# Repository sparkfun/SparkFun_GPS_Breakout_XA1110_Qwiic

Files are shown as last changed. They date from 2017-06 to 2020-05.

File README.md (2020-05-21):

SparkFun GPS Breakout - XA1110
========================================

SparkFun GPS Breakout - XA1110 (Qwiic) (https://www.sparkfun.com/products/14414)

[*SparkFun GPS Breakout - XA1110 (Qwiic) (SEN-14414)*](https://www.sparkfun.com/products/14414)

The Qwiic GPS uses the Titan X1 GPS module with special I2C firmware. This library talks to the GPS module over I2C.

Repository Contents
-------------------

* **/Hardware** - Eagle design files (.brd, .sch)
* **/Libraries** - Libraries for use with the SparkFun GPS Breakout
* **/Production** - Production panel files (.brd)

Documentation
--------------
* **[SparkFun I2C GPS Library](https://github.com/sparkfun/SparkFun_I2C_GPS_Arduino_Library)** - C library for the XA1110.
* **[TinyGPS library by MikalHart](https://github.com/mikalhart/TinyGPS)** - C library for the XA1110.
* **[Hookup Guide](https://learn.sparkfun.com/tutorials/sparkfun-gps-breakout---xa1110-qwiic-hookup-guide)** - Basic hookup guide for the XA1110 GPS.
* **[SparkFun Fritzing repo](https://github.com/sparkfun/Fritzing_Parts)** - Fritzing diagrams for SparkFun products.
* **[SparkFun 3D Model repo](https://github.com/sparkfun/3D_Models)** - 3D models of SparkFun products. 
* **[SparkFun Graphical Datasheets](https://github.com/sparkfun/Graphical_Datasheets)** -Graphical Datasheets for various SparkFun products.

Product Versions
----------------
* [SEN-14414](https://www.sparkfun.com/products/14414)- The Qwiic GPS uses the Titan X1 GPS module with special I2C firmware. This library talks to the GPS module over I2C.

Version History
---------------
* [v1.0.0](https://github.com/sparkfun/SparkFun_GPS_Breakout_XA1110_Qwiic/releases/tag/V_1.0.0) - Initial Release

License Information
-------------------

This product is _**open source**_! 

Please review the LICENSE.md file for license information. 

If you have any questions or concerns on licensing, please contact techsupport@sparkfun.com.

Distributed as-is; no warranty is given.

- Your friends at SparkFun.

_<COLLABORATION CREDIT>_

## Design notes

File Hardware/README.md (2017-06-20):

SparkFun <PRODUCT NAME> Design Files
=====================================

The .sch and .brd files hare are Eagle CAD schematic and PCB design files from SparkFun Electronics.
A freeware version of Eagle can be found [here](http://www.cadsoftusa.com/download-eagle/freeware/).

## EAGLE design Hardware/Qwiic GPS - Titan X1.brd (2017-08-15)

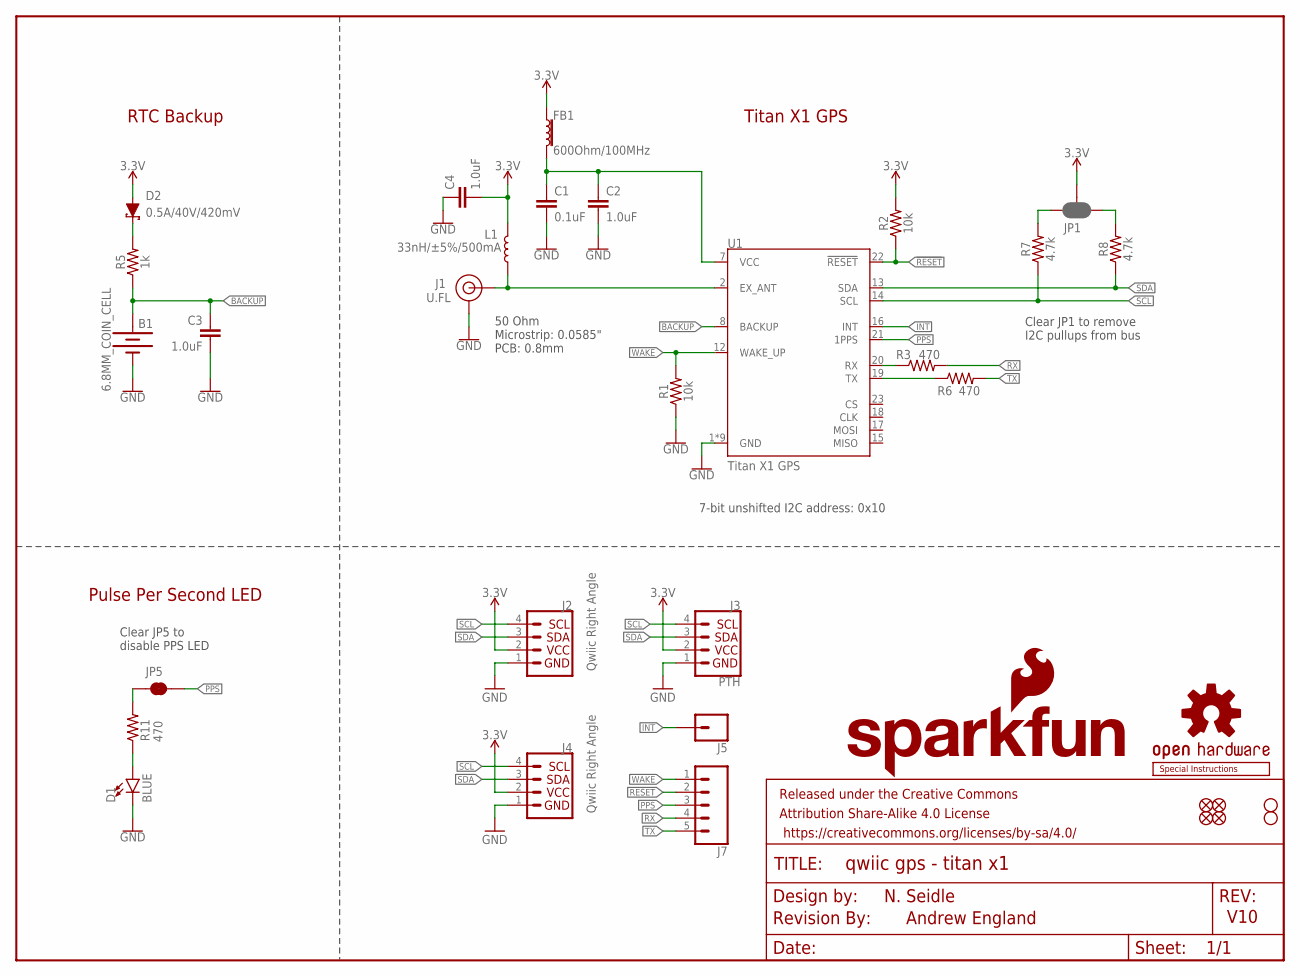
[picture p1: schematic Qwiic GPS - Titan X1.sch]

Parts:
B1: 6.8MM_COIN_CELL; BATTCON-6.8MM
C1: 0.1uF; 0603
C2, C3, C4: 1.0uF; 0603
D1: BLUE; LED-0603
D2: 0.5A/40V/420mV; SOD-323
FB1: 600Ohm/100MHz; 0603
FRAME1: FRAME-LETTER; CREATIVE_COMMONS
J1: U.FL
J2, J4: Qwiic Right Angle; 1X04_1MM_RA
J3: PTH; 1X04_NO_SILK
J5: CONN_01PTH_NO_SILK_YES_STOP; 1X01_NO_SILK
J7: CONN_05NO_SILK; 1X05_NO_SILK
JP1: JUMPER-SMT_3_2-NC_PASTE_SILK; SMT-JUMPER_3_2-NC_PASTE_SILK
JP2, JP6, JP7, JP8: FIDUCIALUFIDUCIAL; MICRO-FIDUCIAL
JP3, JP4: STAND-OFF
JP5: JUMPER-SMT_2_NC_TRACE_NO-SILK; SMT-JUMPER_2_NC_TRACE_NO-SILK
L1: 33nH/±5%/500mA; 0603
LOGO1: OSHW-LOGOMINI; OSHW-LOGO-MINI
LOGO2: SFE_LOGO_NAME_FLAME.1_INCH; SFE_LOGO_NAME_FLAME_.1
LOGO3: REVISION
R1, R2: 10k; 0603
R3, R6, R11: 470; 0603
R5: 1k; 0603
R7, R8: 4.7k; 0603
U1: Titan X1 GPS; TITAN_X1_GPS
U$3: SPECIAL_INSTRUCTIONS-PRODUCTION; PRODUCTION_INSTRUCTIONS

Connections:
3.3V: C4.2, D2.A, FB1.1, J2.2, J3.2 (VCC), J4.2, JP1.2, L1.2, R2.2
!RESET: J7.2, R2.1, U1.22 (!RESET)
BACKUP: B1.+, C3.1, R5.1, U1.8 (BACKUP)
EXT_ANT: J1.FEED (SIGNAL), L1.1, U1.2 (EX_ANT)
GND: B1.-, C1.2, C2.2, C3.2, C4.1, D1.C, J1.1 (GND), J1.2 (GND), J2.1, J3.1 (GND), J4.1, R1.1, U1.1 (GND), U1.3 (GND), U1.4 (GND), U1.5 (GND), U1.6 (GND), U1.9 (GND), U1.10 (GND), U1.11 (GND), U1.24 (GND)
INT: J5.1, U1.16 (INT)
unnamed: D1.A, R11.1
unnamed: JP5.1, R11.2
unnamed: JP1.1, R8.2
unnamed: D2.C, R5.2
unnamed: JP1.3, R7.2
PPS: J7.3, JP5.2, U1.21 (1PPS)
RX: J7.4, R3.2
RXLV: R3.1, U1.20 (RX)
SCL: J2.4, J3.4 (SCL), J4.4, R7.1, U1.14 (SCL)
SDA: J2.3, J3.3 (SDA), J4.3, R8.1, U1.13 (SDA)
TX: J7.5, R6.2
TXLV: R6.1, U1.19 (TX)
VCC_FILTERED: C1.1, C2.1, FB1.2, U1.7 (VCC)
WAKE: J7.1, R1.2, U1.12 (WAKE_UP)

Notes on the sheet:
N. Seidle
V10
7-bit unshifted I2C address: 0x10
Titan X1 GPS
RTC Backup
Pulse Per Second LED
50 Ohm Microstrip: 0.0585" PCB: 0.8mm
Andrew England
Clear JP1 to remove I2C pullups from bus
Clear JP5 to disable PPS LED

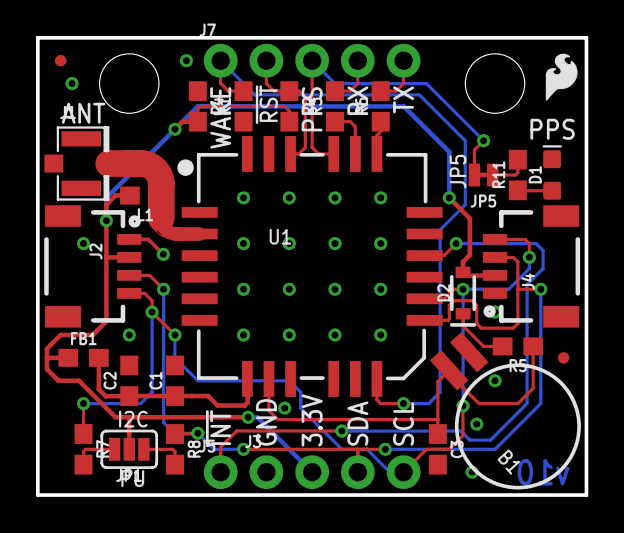
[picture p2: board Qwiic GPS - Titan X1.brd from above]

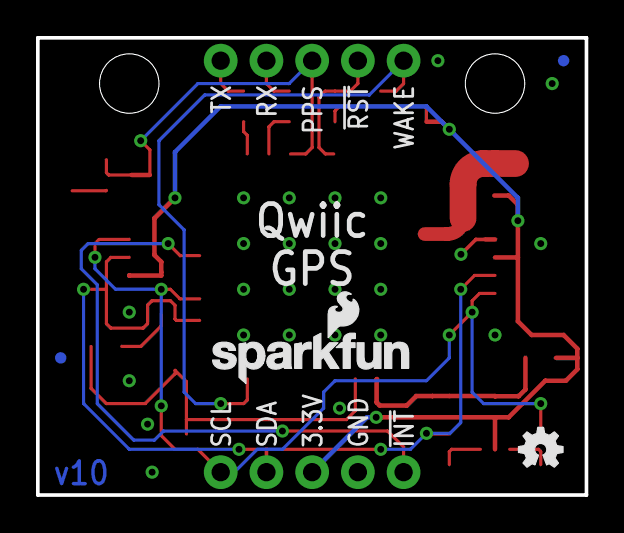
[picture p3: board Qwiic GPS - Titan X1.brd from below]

Board: 2 copper layers, 30.5 x 25.4 mm, 38 parts (4 on the bottom side), 20 nets.

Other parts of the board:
U$2: SFE_LOGO_FLAME_.1

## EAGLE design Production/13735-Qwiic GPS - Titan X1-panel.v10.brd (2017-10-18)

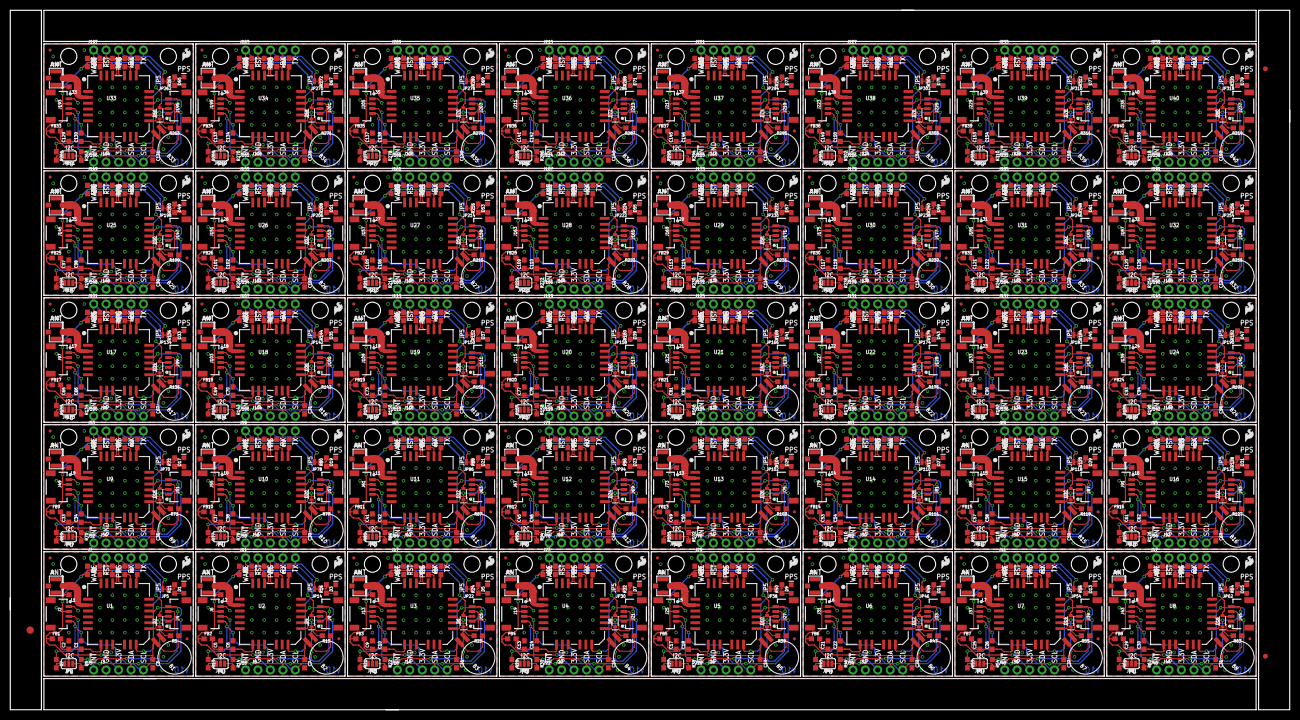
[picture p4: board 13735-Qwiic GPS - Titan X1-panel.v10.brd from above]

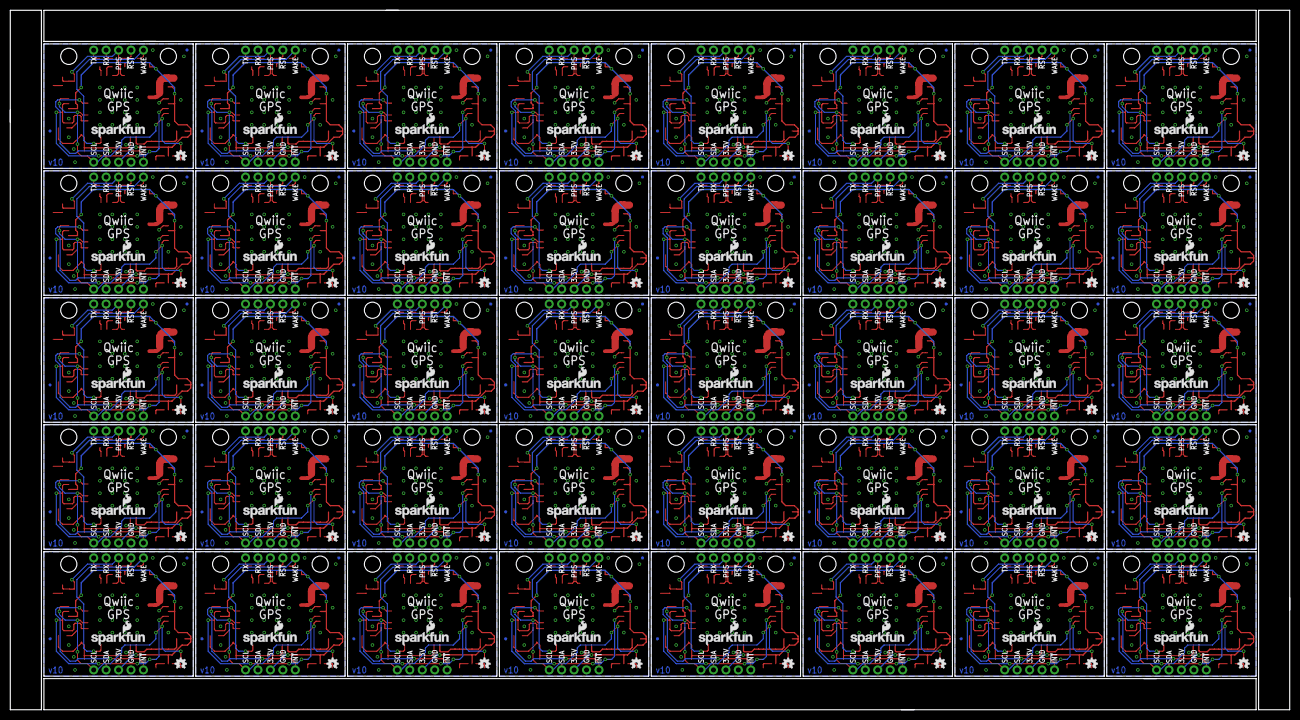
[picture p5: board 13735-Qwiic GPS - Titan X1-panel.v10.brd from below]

Board: 2 copper layers, 261.1 x 142.7 mm, 1403 parts (160 on the bottom side), 800 nets.

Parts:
B1, B2, B3, B4, B5, B6, B7, B8, B9, B10, B11, B12, B13, B14, B15, B16, B17, B18, B19, B20, B21, B22, B23, B24, B25, B26, B27, B28, B29, B30, B31, B32, B33, B34, B35, B36, B37, B38, B39, B40: 6.8MM_COIN_CELL; BATTCON-6.8MM
C1, C6, C10, C14, C18, C22, C26, C30, C34, C38, C42, C46, C50, C54, C58, C62, C66, C70, C74, C78, C82, C86, C90, C94, C98, C102, C106, C110, C114, C118, C122, C126, C130, C134, C138, C142, C146, C150, C154, C158: 0.1uF; 0603
C2, C3, C4, C5, C7, C8, C9, C11, C12, C13, C15, C16, C17, C19, C20, C21, C23, C24, C25, C27, C28, C29, C31, C32, C33, C35, C36, C37, C39, C40, C41, C43, C44, C45, C47, C48, C49, C51, C52, C53, C55, C56, C57, C59, C60, C61, C63, C64, C65, C67, C68, C69, C71, C72, C73, C75, C76, C77, C79, C80, C81, C83, C84, C85, C87, C88, C89, C91, C92, C93, C95, C96, C97, C99, C100, C101, C103, C104, C105, C107, C108, C109, C111, C112, C113, C115, C116, C117, C119, C120, C121, C123, C124, C125, C127, C128, C129, C131, C132, C133, C135, C136, C137, C139, C140, C141, C143, C144, C145, C147, C148, C149, C151, C152, C153, C155, C156, C157, C159, C160: 1.0uF; 0603
D1, D3, D5, D7, D9, D11, D13, D15, D17, D19, D21, D23, D25, D27, D29, D31, D33, D35, D37, D39, D41, D43, D45, D47, D49, D51, D53, D55, D57, D59, D61, D63, D65, D67, D69, D71, D73, D75, D77, D79: BLUE; LED-0603
D2, D4, D6, D8, D10, D12, D14, D16, D18, D20, D22, D24, D26, D28, D30, D32, D34, D36, D38, D40, D42, D44, D46, D48, D50, D52, D54, D56, D58, D60, D62, D64, D66, D68, D70, D72, D74, D76, D78, D80: 0.5A/40V/420mV; SOD-323
E$1: FIDUCIAL-1.5X3
E$7, E$8: FIDUCIAL-1X2
FB1, FB2, FB3, FB4, FB5, FB6, FB7, FB8, FB9, FB10, FB11, FB12, FB13, FB14, FB15, FB16, FB17, FB18, FB19, FB20, FB21, FB22, FB23, FB24, FB25, FB26, FB27, FB28, FB29, FB30, FB31, FB32, FB33, FB34, FB35, FB36, FB37, FB38, FB39, FB40: 600Ohm/100MHz; 0603
J1, J12, J18, J24, J30, J36, J42, J48, J54, J60, J66, J72, J78, J84, J90, J96, J102, J108, J114, J120, J126, J132, J138, J144, J150, J156, J162, J168, J174, J180, J186, J192, J198, J204, J210, J216, J222, J228, J234, J240: U.FL
J2, J4, J6, J9, J13, J15, J19, J21, J25, J27, J31, J33, J37, J39, J43, J45, J49, J51, J55, J57, J61, J63, J67, J69, J73, J75, J79, J81, J85, J87, J91, J93, J97, J99, J103, J105, J109, J111, J115, J117, J121, J123, J127, J129, J133, J135, J139, J141, J145, J147, J151, J153, J157, J159, J163, J165, J169, J171, J175, J177, J181, J183, J187, J189, J193, J195, J199, J201, J205, J207, J211, J213, J217, J219, J223, J225, J229, J231, J235, J237: Qwiic Right Angle; 1X04_1MM_RA
J3, J8, J14, J20, J26, J32, J38, J44, J50, J56, J62, J68, J74, J80, J86, J92, J98, J104, J110, J116, J122, J128, J134, J140, J146, J152, J158, J164, J170, J176, J182, J188, J194, J200, J206, J212, J218, J224, J230, J236: PTH; 1X04_NO_SILK
J5, J10, J16, J22, J28, J34, J40, J46, J52, J58, J64, J70, J76, J82, J88, J94, J100, J106, J112, J118, J124, J130, J136, J142, J148, J154, J160, J166, J172, J178, J184, J190, J196, J202, J208, J214, J220, J226, J232, J238: 1X01_NO_SILK
J7, J11, J17, J23, J29, J35, J41, J47, J53, J59, J65, J71, J77, J83, J89, J95, J101, J107, J113, J119, J125, J131, J137, J143, J149, J155, J161, J167, J173, J179, J185, J191, J197, J203, J209, J215, J221, J227, J233, J239: 1X05_NO_SILK
JP1, JP13, JP21, JP29, JP37, JP45, JP53, JP61, JP69, JP77, JP85, JP93, JP101, JP109, JP117, JP125, JP133, JP141, JP149, JP157, JP165, JP173, JP181, JP189, JP197, JP205, JP213, JP221, JP229, JP237, JP245, JP253, JP261, JP269, JP277, JP285, JP293, JP301, JP309, JP317: SMT-JUMPER_3_2-NC_PASTE_SILK
JP2, JP6, JP7, JP8, JP11, JP12, JP15, JP16, JP19, JP20, JP23, JP24, JP27, JP28, JP31, JP32, JP35, JP36, JP39, JP40, JP43, JP44, JP47, JP48, JP51, JP52, JP55, JP56, JP59, JP60, JP63, JP64, JP67, JP68, JP71, JP72, JP75, JP76, JP79, JP80, JP83, JP84, JP87, JP88, JP91, JP92, JP95, JP96, JP99, JP100, JP103, JP104, JP107, JP108, JP111, JP112, JP115, JP116, JP119, JP120, JP123, JP124, JP127, JP128, JP131, JP132, JP135, JP136, JP139, JP140, JP143, JP144, JP147, JP148, JP151, JP152, JP155, JP156, JP159, JP160, JP163, JP164, JP167, JP168, JP171, JP172, JP175, JP176, JP179, JP180, JP183, JP184, JP187, JP188, JP191, JP192, JP195, JP196, JP199, JP200, JP203, JP204, JP207, JP208, JP211, JP212, JP215, JP216, JP219, JP220, JP223, JP224, JP227, JP228, JP231, JP232, JP235, JP236, JP239, JP240, JP243, JP244, JP247, JP248, JP251, JP252, JP255, JP256, JP259, JP260, JP263, JP264, JP267, JP268, JP271, JP272, JP275, JP276, JP279, JP280, JP283, JP284, JP287, JP288, JP291, JP292, JP295, JP296, JP299, JP300, JP303, JP304, JP307, JP308, JP311, JP312, JP315, JP316, JP319, JP320: FIDUCIALUFIDUCIAL; MICRO-FIDUCIAL
JP3, JP4, JP9, JP10, JP17, JP18, JP25, JP26, JP33, JP34, JP41, JP42, JP49, JP50, JP57, JP58, JP65, JP66, JP73, JP74, JP81, JP82, JP89, JP90, JP97, JP98, JP105, JP106, JP113, JP114, JP121, JP122, JP129, JP130, JP137, JP138, JP145, JP146, JP153, JP154, JP161, JP162, JP169, JP170, JP177, JP178, JP185, JP186, JP193, JP194, JP201, JP202, JP209, JP210, JP217, JP218, JP225, JP226, JP233, JP234, JP241, JP242, JP249, JP250, JP257, JP258, JP265, JP266, JP273, JP274, JP281, JP282, JP289, JP290, JP297, JP298, JP305, JP306, JP313, JP314: STAND-OFF
JP5, JP14, JP22, JP30, JP38, JP46, JP54, JP62, JP70, JP78, JP86, JP94, JP102, JP110, JP118, JP126, JP134, JP142, JP150, JP158, JP166, JP174, JP182, JP190, JP198, JP206, JP214, JP222, JP230, JP238, JP246, JP254, JP262, JP270, JP278, JP286, JP294, JP302, JP310, JP318: SMT-JUMPER_2_NC_TRACE_NO-SILK
L1, L2, L3, L4, L5, L6, L7, L8, L9, L10, L11, L12, L13, L14, L15, L16, L17, L18, L19, L20, L21, L22, L23, L24, L25, L26, L27, L28, L29, L30, L31, L32, L33, L34, L35, L36, L37, L38, L39, L40: 33nH/±5%/500mA; 0603
LOGO1, LOGO3, LOGO5, LOGO7, LOGO9, LOGO11, LOGO13, LOGO15, LOGO17, LOGO19, LOGO21, LOGO23, LOGO25, LOGO27, LOGO29, LOGO31, LOGO33, LOGO35, LOGO37, LOGO39, LOGO41, LOGO43, LOGO45, LOGO47, LOGO49, LOGO51, LOGO53, LOGO55, LOGO57, LOGO59, LOGO61, LOGO63, LOGO65, LOGO67, LOGO69, LOGO71, LOGO73, LOGO75, LOGO77, LOGO79: OSHW-LOGOMINI; OSHW-LOGO-MINI
LOGO2, LOGO4, LOGO6, LOGO8, LOGO10, LOGO12, LOGO14, LOGO16, LOGO18, LOGO20, LOGO22, LOGO24, LOGO26, LOGO28, LOGO30, LOGO32, LOGO34, LOGO36, LOGO38, LOGO40, LOGO42, LOGO44, LOGO46, LOGO48, LOGO50, LOGO52, LOGO54, LOGO56, LOGO58, LOGO60, LOGO62, LOGO64, LOGO66, LOGO68, LOGO70, LOGO72, LOGO74, LOGO76, LOGO78, LOGO80: SFE_LOGO_NAME_FLAME.1_INCH; SFE_LOGO_NAME_FLAME_.1
R1, R2, R4, R9, R17, R18, R25, R26, R33, R34, R41, R42, R49, R50, R57, R58, R65, R66, R73, R74, R81, R82, R89, R90, R97, R98, R105, R106, R113, R114, R121, R122, R129, R130, R137, R138, R145, R146, R153, R154, R161, R162, R169, R170, R177, R178, R185, R186, R193, R194, R201, R202, R209, R210, R217, R218, R225, R226, R233, R234, R241, R242, R249, R250, R257, R258, R265, R266, R273, R274, R281, R282, R289, R290, R297, R298, R305, R306, R313, R314: 10k; 0603
R3, R6, R10, R11, R12, R16, R19, R20, R24, R27, R28, R32, R35, R36, R40, R43, R44, R48, R51, R52, R56, R59, R60, R64, R67, R68, R72, R75, R76, R80, R83, R84, R88, R91, R92, R96, R99, R100, R104, R107, R108, R112, R115, R116, R120, R123, R124, R128, R131, R132, R136, R139, R140, R144, R147, R148, R152, R155, R156, R160, R163, R164, R168, R171, R172, R176, R179, R180, R184, R187, R188, R192, R195, R196, R200, R203, R204, R208, R211, R212, R216, R219, R220, R224, R227, R228, R232, R235, R236, R240, R243, R244, R248, R251, R252, R256, R259, R260, R264, R267, R268, R272, R275, R276, R280, R283, R284, R288, R291, R292, R296, R299, R300, R304, R307, R308, R312, R315, R316, R320: 470; 0603
R5, R15, R23, R31, R39, R47, R55, R63, R71, R79, R87, R95, R103, R111, R119, R127, R135, R143, R151, R159, R167, R175, R183, R191, R199, R207, R215, R223, R231, R239, R247, R255, R263, R271, R279, R287, R295, R303, R311, R319: 1k; 0603
R7, R8, R13, R14, R21, R22, R29, R30, R37, R38, R45, R46, R53, R54, R61, R62, R69, R70, R77, R78, R85, R86, R93, R94, R101, R102, R109, R110, R117, R118, R125, R126, R133, R134, R141, R142, R149, R150, R157, R158, R165, R166, R173, R174, R181, R182, R189, R190, R197, R198, R205, R206, R213, R214, R221, R222, R229, R230, R237, R238, R245, R246, R253, R254, R261, R262, R269, R270, R277, R278, R285, R286, R293, R294, R301, R302, R309, R310, R317, R318: 4.7k; 0603
U1, U2, U3, U4, U5, U6, U7, U8, U9, U10, U11, U12, U13, U14, U15, U16, U17, U18, U19, U20, U21, U22, U23, U24, U25, U26, U27, U28, U29, U30, U31, U32, U33, U34, U35, U36, U37, U38, U39, U40: Titan X1 GPS; TITAN_X1_GPS
U$1, U$2, U$3, U$4, U$5, U$6, U$7, U$8, U$9, U$10, U$11, U$12, U$13, U$14, U$15, U$16, U$17, U$18, U$19, U$20, U$21, U$22, U$23, U$24, U$25, U$26, U$27, U$28, U$29, U$30, U$31, U$32, U$33, U$34, U$35, U$36, U$37, U$38, U$39, U$40: SFE_LOGO_FLAME_.1

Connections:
3.3V: C4.2, D2.A, FB1.1, J2.2, J3.2, J4.2, JP1.2, L1.2, R2.2
3.3V1: C8.2, D4.A, FB2.1, J6.2, J8.2, J9.2, JP13.2, L2.2, R9.2
3.3V2: C12.2, D6.A, FB3.1, J13.2, J14.2, J15.2, JP21.2, L3.2, R18.2
3.3V3: C16.2, D8.A, FB4.1, J19.2, J20.2, J21.2, JP29.2, L4.2, R26.2
3.3V4: C20.2, D10.A, FB5.1, J25.2, J26.2, J27.2, JP37.2, L5.2, R34.2
3.3V5: C24.2, D12.A, FB6.1, J31.2, J32.2, J33.2, JP45.2, L6.2, R42.2
3.3V6: C28.2, D14.A, FB7.1, J37.2, J38.2, J39.2, JP53.2, L7.2, R50.2
3.3V7: C32.2, D16.A, FB8.1, J43.2, J44.2, J45.2, JP61.2, L8.2, R58.2
3.3V8: C36.2, D18.A, FB9.1, J49.2, J50.2, J51.2, JP69.2, L9.2, R66.2
3.3V9: C40.2, D20.A, FB10.1, J55.2, J56.2, J57.2, JP77.2, L10.2, R74.2
3.3V10: C44.2, D22.A, FB11.1, J61.2, J62.2, J63.2, JP85.2, L11.2, R82.2
3.3V11: C48.2, D24.A, FB12.1, J67.2, J68.2, J69.2, JP93.2, L12.2, R90.2
3.3V12: C52.2, D26.A, FB13.1, J73.2, J74.2, J75.2, JP101.2, L13.2, R98.2
3.3V13: C56.2, D28.A, FB14.1, J79.2, J80.2, J81.2, JP109.2, L14.2, R106.2
3.3V14: C60.2, D30.A, FB15.1, J85.2, J86.2, J87.2, JP117.2, L15.2, R114.2
3.3V15: C64.2, D32.A, FB16.1, J91.2, J92.2, J93.2, JP125.2, L16.2, R122.2
3.3V16: C68.2, D34.A, FB17.1, J97.2, J98.2, J99.2, JP133.2, L17.2, R130.2
3.3V17: C72.2, D36.A, FB18.1, J103.2, J104.2, J105.2, JP141.2, L18.2, R138.2
3.3V18: C76.2, D38.A, FB19.1, J109.2, J110.2, J111.2, JP149.2, L19.2, R146.2
3.3V19: C80.2, D40.A, FB20.1, J115.2, J116.2, J117.2, JP157.2, L20.2, R154.2
3.3V20: C84.2, D42.A, FB21.1, J121.2, J122.2, J123.2, JP165.2, L21.2, R162.2
3.3V21: C88.2, D44.A, FB22.1, J127.2, J128.2, J129.2, JP173.2, L22.2, R170.2
3.3V22: C92.2, D46.A, FB23.1, J133.2, J134.2, J135.2, JP181.2, L23.2, R178.2
3.3V23: C96.2, D48.A, FB24.1, J139.2, J140.2, J141.2, JP189.2, L24.2, R186.2
3.3V24: C100.2, D50.A, FB25.1, J145.2, J146.2, J147.2, JP197.2, L25.2, R194.2
3.3V25: C104.2, D52.A, FB26.1, J151.2, J152.2, J153.2, JP205.2, L26.2, R202.2
3.3V26: C108.2, D54.A, FB27.1, J157.2, J158.2, J159.2, JP213.2, L27.2, R210.2
3.3V27: C112.2, D56.A, FB28.1, J163.2, J164.2, J165.2, JP221.2, L28.2, R218.2
3.3V28: C116.2, D58.A, FB29.1, J169.2, J170.2, J171.2, JP229.2, L29.2, R226.2
3.3V29: C120.2, D60.A, FB30.1, J175.2, J176.2, J177.2, JP237.2, L30.2, R234.2
3.3V30: C124.2, D62.A, FB31.1, J181.2, J182.2, J183.2, JP245.2, L31.2, R242.2
3.3V31: C128.2, D64.A, FB32.1, J187.2, J188.2, J189.2, JP253.2, L32.2, R250.2
3.3V32: C132.2, D66.A, FB33.1, J193.2, J194.2, J195.2, JP261.2, L33.2, R258.2
3.3V33: C136.2, D68.A, FB34.1, J199.2, J200.2, J201.2, JP269.2, L34.2, R266.2
3.3V34: C140.2, D70.A, FB35.1, J205.2, J206.2, J207.2, JP277.2, L35.2, R274.2
3.3V35: C144.2, D72.A, FB36.1, J211.2, J212.2, J213.2, JP285.2, L36.2, R282.2
3.3V36: C148.2, D74.A, FB37.1, J217.2, J218.2, J219.2, JP293.2, L37.2, R290.2
3.3V37: C152.2, D76.A, FB38.1, J223.2, J224.2, J225.2, JP301.2, L38.2, R298.2
3.3V38: C156.2, D78.A, FB39.1, J229.2, J230.2, J231.2, JP309.2, L39.2, R306.2
3.3V39: C160.2, D80.A, FB40.1, J235.2, J236.2, J237.2, JP317.2, L40.2, R314.2
!RESET: J7.2, R2.1, U1.22
!RESET1: J11.2, R9.1, U2.22
!RESET2: J17.2, R18.1, U3.22
!RESET3: J23.2, R26.1, U4.22
!RESET4: J29.2, R34.1, U5.22
!RESET5: J35.2, R42.1, U6.22
!RESET6: J41.2, R50.1, U7.22
!RESET7: J47.2, R58.1, U8.22
!RESET8: J53.2, R66.1, U9.22
!RESET9: J59.2, R74.1, U10.22
!RESET10: J65.2, R82.1, U11.22
!RESET11: J71.2, R90.1, U12.22
!RESET12: J77.2, R98.1, U13.22
!RESET13: J83.2, R106.1, U14.22
!RESET14: J89.2, R114.1, U15.22
!RESET15: J95.2, R122.1, U16.22
!RESET16: J101.2, R130.1, U17.22
!RESET17: J107.2, R138.1, U18.22
!RESET18: J113.2, R146.1, U19.22
!RESET19: J119.2, R154.1, U20.22
!RESET20: J125.2, R162.1, U21.22
!RESET21: J131.2, R170.1, U22.22
!RESET22: J137.2, R178.1, U23.22
!RESET23: J143.2, R186.1, U24.22
!RESET24: J149.2, R194.1, U25.22
!RESET25: J155.2, R202.1, U26.22
!RESET26: J161.2, R210.1, U27.22
!RESET27: J167.2, R218.1, U28.22
!RESET28: J173.2, R226.1, U29.22
!RESET29: J179.2, R234.1, U30.22
!RESET30: J185.2, R242.1, U31.22
!RESET31: J191.2, R250.1, U32.22
!RESET32: J197.2, R258.1, U33.22
!RESET33: J203.2, R266.1, U34.22
!RESET34: J209.2, R274.1, U35.22
!RESET35: J215.2, R282.1, U36.22
!RESET36: J221.2, R290.1, U37.22
!RESET37: J227.2, R298.1, U38.22
!RESET38: J233.2, R306.1, U39.22
!RESET39: J239.2, R314.1, U40.22
BACKUP: B1.+, C3.1, R5.1, U1.8
BACKUP1: B2.+, C7.1, R15.1, U2.8
BACKUP2: B3.+, C11.1, R23.1, U3.8
BACKUP3: B4.+, C15.1, R31.1, U4.8
BACKUP4: B5.+, C19.1, R39.1, U5.8
BACKUP5: B6.+, C23.1, R47.1, U6.8
BACKUP6: B7.+, C27.1, R55.1, U7.8
BACKUP7: B8.+, C31.1, R63.1, U8.8
BACKUP8: B9.+, C35.1, R71.1, U9.8
BACKUP9: B10.+, C39.1, R79.1, U10.8
BACKUP10: B11.+, C43.1, R87.1, U11.8
BACKUP11: B12.+, C47.1, R95.1, U12.8
BACKUP12: B13.+, C51.1, R103.1, U13.8
BACKUP13: B14.+, C55.1, R111.1, U14.8
BACKUP14: B15.+, C59.1, R119.1, U15.8
BACKUP15: B16.+, C63.1, R127.1, U16.8
BACKUP16: B17.+, C67.1, R135.1, U17.8
BACKUP17: B18.+, C71.1, R143.1, U18.8
BACKUP18: B19.+, C75.1, R151.1, U19.8
BACKUP19: B20.+, C79.1, R159.1, U20.8
BACKUP20: B21.+, C83.1, R167.1, U21.8
BACKUP21: B22.+, C87.1, R175.1, U22.8
BACKUP22: B23.+, C91.1, R183.1, U23.8
BACKUP23: B24.+, C95.1, R191.1, U24.8
BACKUP24: B25.+, C99.1, R199.1, U25.8
BACKUP25: B26.+, C103.1, R207.1, U26.8
BACKUP26: B27.+, C107.1, R215.1, U27.8
BACKUP27: B28.+, C111.1, R223.1, U28.8
BACKUP28: B29.+, C115.1, R231.1, U29.8
BACKUP29: B30.+, C119.1, R239.1, U30.8
BACKUP30: B31.+, C123.1, R247.1, U31.8
BACKUP31: B32.+, C127.1, R255.1, U32.8
BACKUP32: B33.+, C131.1, R263.1, U33.8
BACKUP33: B34.+, C135.1, R271.1, U34.8
BACKUP34: B35.+, C139.1, R279.1, U35.8
BACKUP35: B36.+, C143.1, R287.1, U36.8
BACKUP36: B37.+, C147.1, R295.1, U37.8
BACKUP37: B38.+, C151.1, R303.1, U38.8
BACKUP38: B39.+, C155.1, R311.1, U39.8
BACKUP39: B40.+, C159.1, R319.1, U40.8
EXT_ANT: J1.FEED, L1.1, U1.2
EXT_ANT1: J12.FEED, L2.1, U2.2
EXT_ANT2: J18.FEED, L3.1, U3.2
EXT_ANT3: J24.FEED, L4.1, U4.2
EXT_ANT4: J30.FEED, L5.1, U5.2
EXT_ANT5: J36.FEED, L6.1, U6.2
EXT_ANT6: J42.FEED, L7.1, U7.2
EXT_ANT7: J48.FEED, L8.1, U8.2
EXT_ANT8: J54.FEED, L9.1, U9.2
EXT_ANT9: J60.FEED, L10.1, U10.2
EXT_ANT10: J66.FEED, L11.1, U11.2
EXT_ANT11: J72.FEED, L12.1, U12.2
EXT_ANT12: J78.FEED, L13.1, U13.2
EXT_ANT13: J84.FEED, L14.1, U14.2
EXT_ANT14: J90.FEED, L15.1, U15.2
EXT_ANT15: J96.FEED, L16.1, U16.2
EXT_ANT16: J102.FEED, L17.1, U17.2
EXT_ANT17: J108.FEED, L18.1, U18.2
EXT_ANT18: J114.FEED, L19.1, U19.2
EXT_ANT19: J120.FEED, L20.1, U20.2
EXT_ANT20: J126.FEED, L21.1, U21.2
EXT_ANT21: J132.FEED, L22.1, U22.2
EXT_ANT22: J138.FEED, L23.1, U23.2
EXT_ANT23: J144.FEED, L24.1, U24.2
EXT_ANT24: J150.FEED, L25.1, U25.2
EXT_ANT25: J156.FEED, L26.1, U26.2
EXT_ANT26: J162.FEED, L27.1, U27.2
EXT_ANT27: J168.FEED, L28.1, U28.2
EXT_ANT28: J174.FEED, L29.1, U29.2
EXT_ANT29: J180.FEED, L30.1, U30.2
EXT_ANT30: J186.FEED, L31.1, U31.2
EXT_ANT31: J192.FEED, L32.1, U32.2
EXT_ANT32: J198.FEED, L33.1, U33.2
EXT_ANT33: J204.FEED, L34.1, U34.2
EXT_ANT34: J210.FEED, L35.1, U35.2
EXT_ANT35: J216.FEED, L36.1, U36.2
EXT_ANT36: J222.FEED, L37.1, U37.2
EXT_ANT37: J228.FEED, L38.1, U38.2
EXT_ANT38: J234.FEED, L39.1, U39.2
EXT_ANT39: J240.FEED, L40.1, U40.2
GND: B1.-, C1.2, C2.2, C3.2, C4.1, D1.C, J1.1, J1.2, J2.1, J3.1, J4.1, R1.1, U1.1, U1.3, U1.4, U1.5, U1.6, U1.9, U1.10, U1.11, U1.24
GND1: B2.-, C5.2, C6.2, C7.2, C8.1, D3.C, J6.1, J8.1, J9.1, J12.1, J12.2, R4.1, U2.1, U2.3, U2.4, U2.5, U2.6, U2.9, U2.10, U2.11, U2.24
GND2: B3.-, C9.2, C10.2, C11.2, C12.1, D5.C, J13.1, J14.1, J15.1, J18.1, J18.2, R17.1, U3.1, U3.3, U3.4, U3.5, U3.6, U3.9, U3.10, U3.11, U3.24
GND3: B4.-, C13.2, C14.2, C15.2, C16.1, D7.C, J19.1, J20.1, J21.1, J24.1, J24.2, R25.1, U4.1, U4.3, U4.4, U4.5, U4.6, U4.9, U4.10, U4.11, U4.24
GND4: B5.-, C17.2, C18.2, C19.2, C20.1, D9.C, J25.1, J26.1, J27.1, J30.1, J30.2, R33.1, U5.1, U5.3, U5.4, U5.5, U5.6, U5.9, U5.10, U5.11, U5.24
GND5: B6.-, C21.2, C22.2, C23.2, C24.1, D11.C, J31.1, J32.1, J33.1, J36.1, J36.2, R41.1, U6.1, U6.3, U6.4, U6.5, U6.6, U6.9, U6.10, U6.11, U6.24
GND6: B7.-, C25.2, C26.2, C27.2, C28.1, D13.C, J37.1, J38.1, J39.1, J42.1, J42.2, R49.1, U7.1, U7.3, U7.4, U7.5, U7.6, U7.9, U7.10, U7.11, U7.24
GND7: B8.-, C29.2, C30.2, C31.2, C32.1, D15.C, J43.1, J44.1, J45.1, J48.1, J48.2, R57.1, U8.1, U8.3, U8.4, U8.5, U8.6, U8.9, U8.10, U8.11, U8.24
GND8: B9.-, C33.2, C34.2, C35.2, C36.1, D17.C, J49.1, J50.1, J51.1, J54.1, J54.2, R65.1, U9.1, U9.3, U9.4, U9.5, U9.6, U9.9, U9.10, U9.11, U9.24
GND9: B10.-, C37.2, C38.2, C39.2, C40.1, D19.C, J55.1, J56.1, J57.1, J60.1, J60.2, R73.1, U10.1, U10.3, U10.4, U10.5, U10.6, U10.9, U10.10, U10.11, U10.24
GND10: B11.-, C41.2, C42.2, C43.2, C44.1, D21.C, J61.1, J62.1, J63.1, J66.1, J66.2, R81.1, U11.1, U11.3, U11.4, U11.5, U11.6, U11.9, U11.10, U11.11, U11.24
GND11: B12.-, C45.2, C46.2, C47.2, C48.1, D23.C, J67.1, J68.1, J69.1, J72.1, J72.2, R89.1, U12.1, U12.3, U12.4, U12.5, U12.6, U12.9, U12.10, U12.11, U12.24
GND12: B13.-, C49.2, C50.2, C51.2, C52.1, D25.C, J73.1, J74.1, J75.1, J78.1, J78.2, R97.1, U13.1, U13.3, U13.4, U13.5, U13.6, U13.9, U13.10, U13.11, U13.24
GND13: B14.-, C53.2, C54.2, C55.2, C56.1, D27.C, J79.1, J80.1, J81.1, J84.1, J84.2, R105.1, U14.1, U14.3, U14.4, U14.5, U14.6, U14.9, U14.10, U14.11, U14.24
GND14: B15.-, C57.2, C58.2, C59.2, C60.1, D29.C, J85.1, J86.1, J87.1, J90.1, J90.2, R113.1, U15.1, U15.3, U15.4, U15.5, U15.6, U15.9, U15.10, U15.11, U15.24
GND15: B16.-, C61.2, C62.2, C63.2, C64.1, D31.C, J91.1, J92.1, J93.1, J96.1, J96.2, R121.1, U16.1, U16.3, U16.4, U16.5, U16.6, U16.9, U16.10, U16.11, U16.24
GND16: B17.-, C65.2, C66.2, C67.2, C68.1, D33.C, J97.1, J98.1, J99.1, J102.1, J102.2, R129.1, U17.1, U17.3, U17.4, U17.5, U17.6, U17.9, U17.10, U17.11, U17.24
GND17: B18.-, C69.2, C70.2, C71.2, C72.1, D35.C, J103.1, J104.1, J105.1, J108.1, J108.2, R137.1, U18.1, U18.3, U18.4, U18.5, U18.6, U18.9, U18.10, U18.11, U18.24
GND18: B19.-, C73.2, C74.2, C75.2, C76.1, D37.C, J109.1, J110.1, J111.1, J114.1, J114.2, R145.1, U19.1, U19.3, U19.4, U19.5, U19.6, U19.9, U19.10, U19.11, U19.24
GND19: B20.-, C77.2, C78.2, C79.2, C80.1, D39.C, J115.1, J116.1, J117.1, J120.1, J120.2, R153.1, U20.1, U20.3, U20.4, U20.5, U20.6, U20.9, U20.10, U20.11, U20.24
GND20: B21.-, C81.2, C82.2, C83.2, C84.1, D41.C, J121.1, J122.1, J123.1, J126.1, J126.2, R161.1, U21.1, U21.3, U21.4, U21.5, U21.6, U21.9, U21.10, U21.11, U21.24
GND21: B22.-, C85.2, C86.2, C87.2, C88.1, D43.C, J127.1, J128.1, J129.1, J132.1, J132.2, R169.1, U22.1, U22.3, U22.4, U22.5, U22.6, U22.9, U22.10, U22.11, U22.24
GND22: B23.-, C89.2, C90.2, C91.2, C92.1, D45.C, J133.1, J134.1, J135.1, J138.1, J138.2, R177.1, U23.1, U23.3, U23.4, U23.5, U23.6, U23.9, U23.10, U23.11, U23.24
GND23: B24.-, C93.2, C94.2, C95.2, C96.1, D47.C, J139.1, J140.1, J141.1, J144.1, J144.2, R185.1, U24.1, U24.3, U24.4, U24.5, U24.6, U24.9, U24.10, U24.11, U24.24
GND24: B25.-, C97.2, C98.2, C99.2, C100.1, D49.C, J145.1, J146.1, J147.1, J150.1, J150.2, R193.1, U25.1, U25.3, U25.4, U25.5, U25.6, U25.9, U25.10, U25.11, U25.24
GND25: B26.-, C101.2, C102.2, C103.2, C104.1, D51.C, J151.1, J152.1, J153.1, J156.1, J156.2, R201.1, U26.1, U26.3, U26.4, U26.5, U26.6, U26.9, U26.10, U26.11, U26.24
GND26: B27.-, C105.2, C106.2, C107.2, C108.1, D53.C, J157.1, J158.1, J159.1, J162.1, J162.2, R209.1, U27.1, U27.3, U27.4, U27.5, U27.6, U27.9, U27.10, U27.11, U27.24
GND27: B28.-, C109.2, C110.2, C111.2, C112.1, D55.C, J163.1, J164.1, J165.1, J168.1, J168.2, R217.1, U28.1, U28.3, U28.4, U28.5, U28.6, U28.9, U28.10, U28.11, U28.24
GND28: B29.-, C113.2, C114.2, C115.2, C116.1, D57.C, J169.1, J170.1, J171.1, J174.1, J174.2, R225.1, U29.1, U29.3, U29.4, U29.5, U29.6, U29.9, U29.10, U29.11, U29.24
GND29: B30.-, C117.2, C118.2, C119.2, C120.1, D59.C, J175.1, J176.1, J177.1, J180.1, J180.2, R233.1, U30.1, U30.3, U30.4, U30.5, U30.6, U30.9, U30.10, U30.11, U30.24
GND30: B31.-, C121.2, C122.2, C123.2, C124.1, D61.C, J181.1, J182.1, J183.1, J186.1, J186.2, R241.1, U31.1, U31.3, U31.4, U31.5, U31.6, U31.9, U31.10, U31.11, U31.24
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

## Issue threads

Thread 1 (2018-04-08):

python library for raspberry pi?

ckoven, 2018-04-08:
Hi All -- do you have any plans to include a python library for using the XA1110 GPS via the i2c interface on a raspberry pi?  Thanks for any info or help you can offer!

ckoven, 2018-04-08:
great! I'd love to but don't have the right skills. thanks!

bboyho, 2020-05-21:
@ckoven , I'm not sure if you are aware but the library has been released for a while => [https://github.com/sparkfun/Qwiic_Titan_Gps_Py](https://github.com/sparkfun/Qwiic_Titan_Gps_Py).

Closing this out. =)

Closed 2020-05-21.

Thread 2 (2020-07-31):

XA1110 Sleep Mode

will2055, 2020-07-31:
The old Titan Datasheet doesn't have a compatible sleep command/procedure. After looking the following datasheet, a solution was found:

http://www.alphamicrowireless.com/media/570768/41111121%20-%20airprime%20xm_xa%20series%20software%20user%20guide_r1.pdf

Forum post detailing solution is also found here: https://forum.sparkfun.com/viewtopic.php?p=211562#p211562

Go to Sleep: `myI2CGPS.createMTKpacket(161,",0");    //161 is "Standby", 0 ==> "Sleep"`

Wake from Sleep: `myI2CGPS.createMTKpacket(225,",4");    //255 is "Periodic Mode", ==> "Perpetual Mode"`

ajakef, 2024-10-29:
I'd like to suggest a correction. I believe command (161, ",0") is not so much "standby" as "go unresponsive until next power cycle". And I think (255, ",4") is not "wake from sleep"; it's "sleep and do not respond to any commands until WAKE pin is pulled high, and start with fresh configuration".

Also, the link above is broken and I believe this is the correct link: https://cdn.sparkfun.com/assets/b/c/4/4/5/AirPrime_XM_XA_Series_Software_User_Guide_r3.pdf.

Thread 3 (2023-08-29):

Sparkfun GPS library, TWI excessive error rate

rtdgreg, 2023-08-29:
I have tried using Sparkfun GPS library to connect Arduino Nano to MT3333 GPS via I2C/TWI physical connection.  I am satisfied this is periodically losing individual single characters from the inbound data stream.  GPS is sending NMEA compliant sentences, but the receiving application program is occasionally not receiving onecharacter that the GPS has sent.  Therefore the appropriate sentence is deemed to be invalid because checksum reported does not match computed checksum.  I have been trying to receive one GNRMC sentence every 100 milliseconds. Error rate is approximately one message in four.  I know the GPS is sending valid messages because error rate drops from 25% to zero if, instead of using the Sparkfun library, I use the Adafruit GPS library.  I am happy to share my test program that demonstrates this issue .

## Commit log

2017-06-16 added eagle files
    [Qwiic GPS - Titan X1.brd, Qwiic GPS - Titan X1.sch]
2017-06-20 Updated file structure to match SFE repo
    [Qwiic GPS - Titan X1.brd, Qwiic GPS - Titan X1.sch]
2017-06-20 Added SparkX models to Sparkfun Library
    [Qwiic GPS - Titan X1.brd, Qwiic GPS - Titan X1.sch]
2017-07-07 fixed DRC errors, updated board to meet checklist
    [Board_Design_Checklist.xls, Board_Design_Checklist_Qwiic Titan X1 GPS_.xls, Qwiic GPS - Titan X1.brd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]
2017-07-12 Added jumper functions to schematic and board
    [Qwiic GPS - Titan X1.brd, Qwiic GPS - Titan X1.sch]
2017-07-12 Post design review changes fixed
    [Qwiic GPS - Titan X1.brd]
2017-07-13 changed corner of GPS package
    [Qwiic GPS - Titan X1.brd, Qwiic GPS - Titan X1.sch]
2017-07-18 V02 changed some net issues, board thicknessinstruction
    [Qwiic GPS - Titan X1.brd, Qwiic GPS - Titan X1.sch]
2017-07-25 changed version
    [Qwiic GPS - Titan X1.brd]
2017-08-15 Changed version number, moved int pin to be compatible with arduino, added jumper label for pps led
    [Qwiic GPS - Titan X1.brd, Qwiic GPS - Titan X1.sch]
2017-08-15 fixed dimensions
    [Qwiic GPS - Titan X1.brd]
2017-08-15 updated version number
    [Qwiic GPS - Titan X1.brd, Qwiic GPS - Titan X1.sch]
2017-08-23 Moved engineering checklist
    [Board_Design_Checklist.xls, Board_Design_Checklist_Qwiic Titan X1 GPS_.xls, Board_Design_Checklist__.xls]
2017-10-18 preparing library for release
    [Board_Design_Checklist__.xls]
2017-10-18 Squashed 'Libraries/Arduino/' content from commit e522651
    git-subtree-dir: Libraries/Arduino
    git-subtree-split: e52265138e1c272fa5e4aa6fda785ac866e6cf0d

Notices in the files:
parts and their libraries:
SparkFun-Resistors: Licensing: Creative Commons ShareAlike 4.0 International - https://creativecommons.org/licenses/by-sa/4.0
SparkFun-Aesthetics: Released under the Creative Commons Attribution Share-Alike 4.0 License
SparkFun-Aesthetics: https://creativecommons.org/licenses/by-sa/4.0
